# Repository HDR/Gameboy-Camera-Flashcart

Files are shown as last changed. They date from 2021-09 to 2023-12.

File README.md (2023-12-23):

## Make sure you read the License (Attribution-NonCommercial-ShareAlike 4.0 International)

Purchase on PCBWay (https://www.pcbway.com/project/shareproject/Game_Boy_Camera_Flashcart___2x1MB___FRAM__.html)

Purchase Advanced (https://www.pcbway.com/project/shareproject/Game_Boy_Camera_Flashcart_2x1MB_FRAM_Advanced_PCB_73cba77a.html)

If you want to support me for free (and get 5 USD in new user credit) you can use my PCBWay [Referral link](https://www.pcbway.com/setinvite.aspx?inviteid=388393) when signing up on PCBWay



PCBWay Referral (https://www.pcbway.com/setinvite.aspx?inviteid=388393)

**Make sure you read the License!**

**Flashing:**

Flashing has only been tested with a [GBxCart](https://www.insidegadgets.com/projects/gbxcart-rw/), flashing both 1MB sections requires [this custom software](GBxCart_RW_GB_Camera_2x1MB_Flasher.zip), which is a modified version of InsideGadget's 2x2MB MBC3 software, or [FlashGBX](https://github.com/lesserkuma/FlashGBX/releases) v3.2 and above.

**BOM:**

| Reference | Part Number | Description |
|-|-|-|
| C1 | [4x4.5mm 22uF](https://www.aliexpress.com/item/32377971645.html) | 22uF 16V 4x4.5 Electrolytic Capacitor |
| C2, C3, C4, C12, C13 | [TCC0603X7R104J500CT](https://www.lcsc.com/product-detail/Multilayer-Ceramic-Capacitors-MLCC-SMD-SMT_CCTC-TCC0603X7R104J500CT_C282518.html) | 100nF 0603 Capacitor |
| C5, C6, C7, C8, C9, C10, C11 | [CC0402KRX7R7BB104](https://lcsc.com/product-detail/Multilayer-Ceramic-Capacitors-MLCC-SMD-SMT_YAGEO-CC0402KRX7R7BB104_C60474.html) | 100nF 0402 Capacitor |
| C14, C15 | [CC0603JRNPO9BN220](https://www.lcsc.com/product-detail/Multilayer-Ceramic-Capacitors-MLCC-SMD-SMT_YAGEO-CC0603JRNPO9BN220_C105620.html) | 22pF 0603 Capacitor |
| R1 | [RC0603JR-071KL](https://www.lcsc.com/product-detail/Chip-Resistor-Surface-Mount_YAGEO-RC0603JR-071KL_C14676.html) | 1K Ω 0603 Resistor |
| D1 | Diode | Harvest D2 from original cartridge |
| J1 | [B9B-ZR-SM4-TF](https://www.aliexpress.com/item/32920487056.html) | Camera Connector, Harvest or buy (JST ZH1.5MM 9 Pin) |
| SW1 | [K3-1296S-E1](https://www.lcsc.com/product-detail/Slide-Switches_Korean-Hroparts-Elec-K3-1296S-E1_C128955.html)| SPDT Switch (For 2x1MB Rom Switching) |
| U1 | MAC-GBD | Harvest U1 from original cartridge |
| U2 | [AM29F016](https://www.aliexpress.com/item/33043533022.html) | 2MB Flash |
| U3 | [FM28V100](https://www.aliexpress.com/item/4001322883101.html) | 1MB FRAM |
| U4 | [TPRT9013-33G](https://www.lcsc.com/product-detail/Linear-Voltage-Regulators-LDO_TECH-PUBLIC-TPRT9013-33GB_C587158.html) | 3.3V Voltage Regulator |

[Interactive BOM](https://martinrefseth.com/ibom/Game%20Boy%20Camera%20Flashcart)

Makes use of [djedditt's](https://github.com/djedditt/s) [gamepak footprint](https://github.com/djedditt/kicad-gamepaks)

Looking for a ready to use flashcart? check out InsideGadgets custom flashcart, the [Insidegadgets' PicNRec AIO](https://shop.insidegadgets.com/product/gameboy-camera-picnrec-aio/)
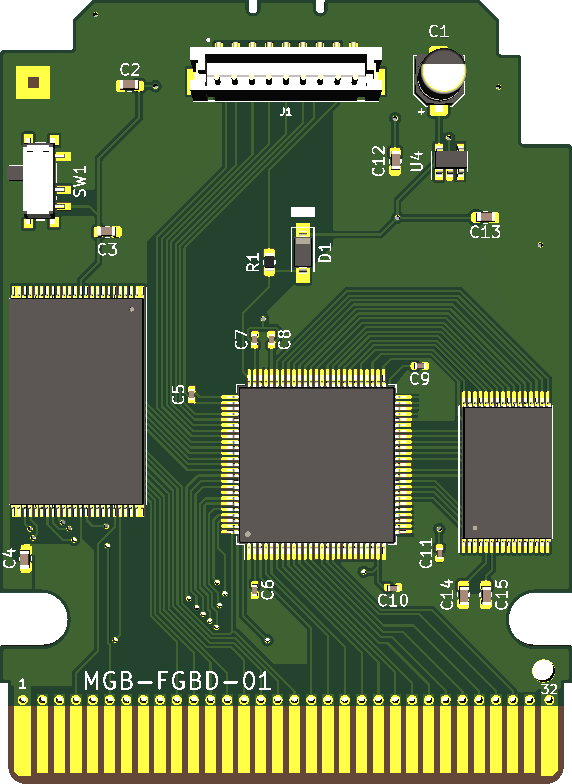
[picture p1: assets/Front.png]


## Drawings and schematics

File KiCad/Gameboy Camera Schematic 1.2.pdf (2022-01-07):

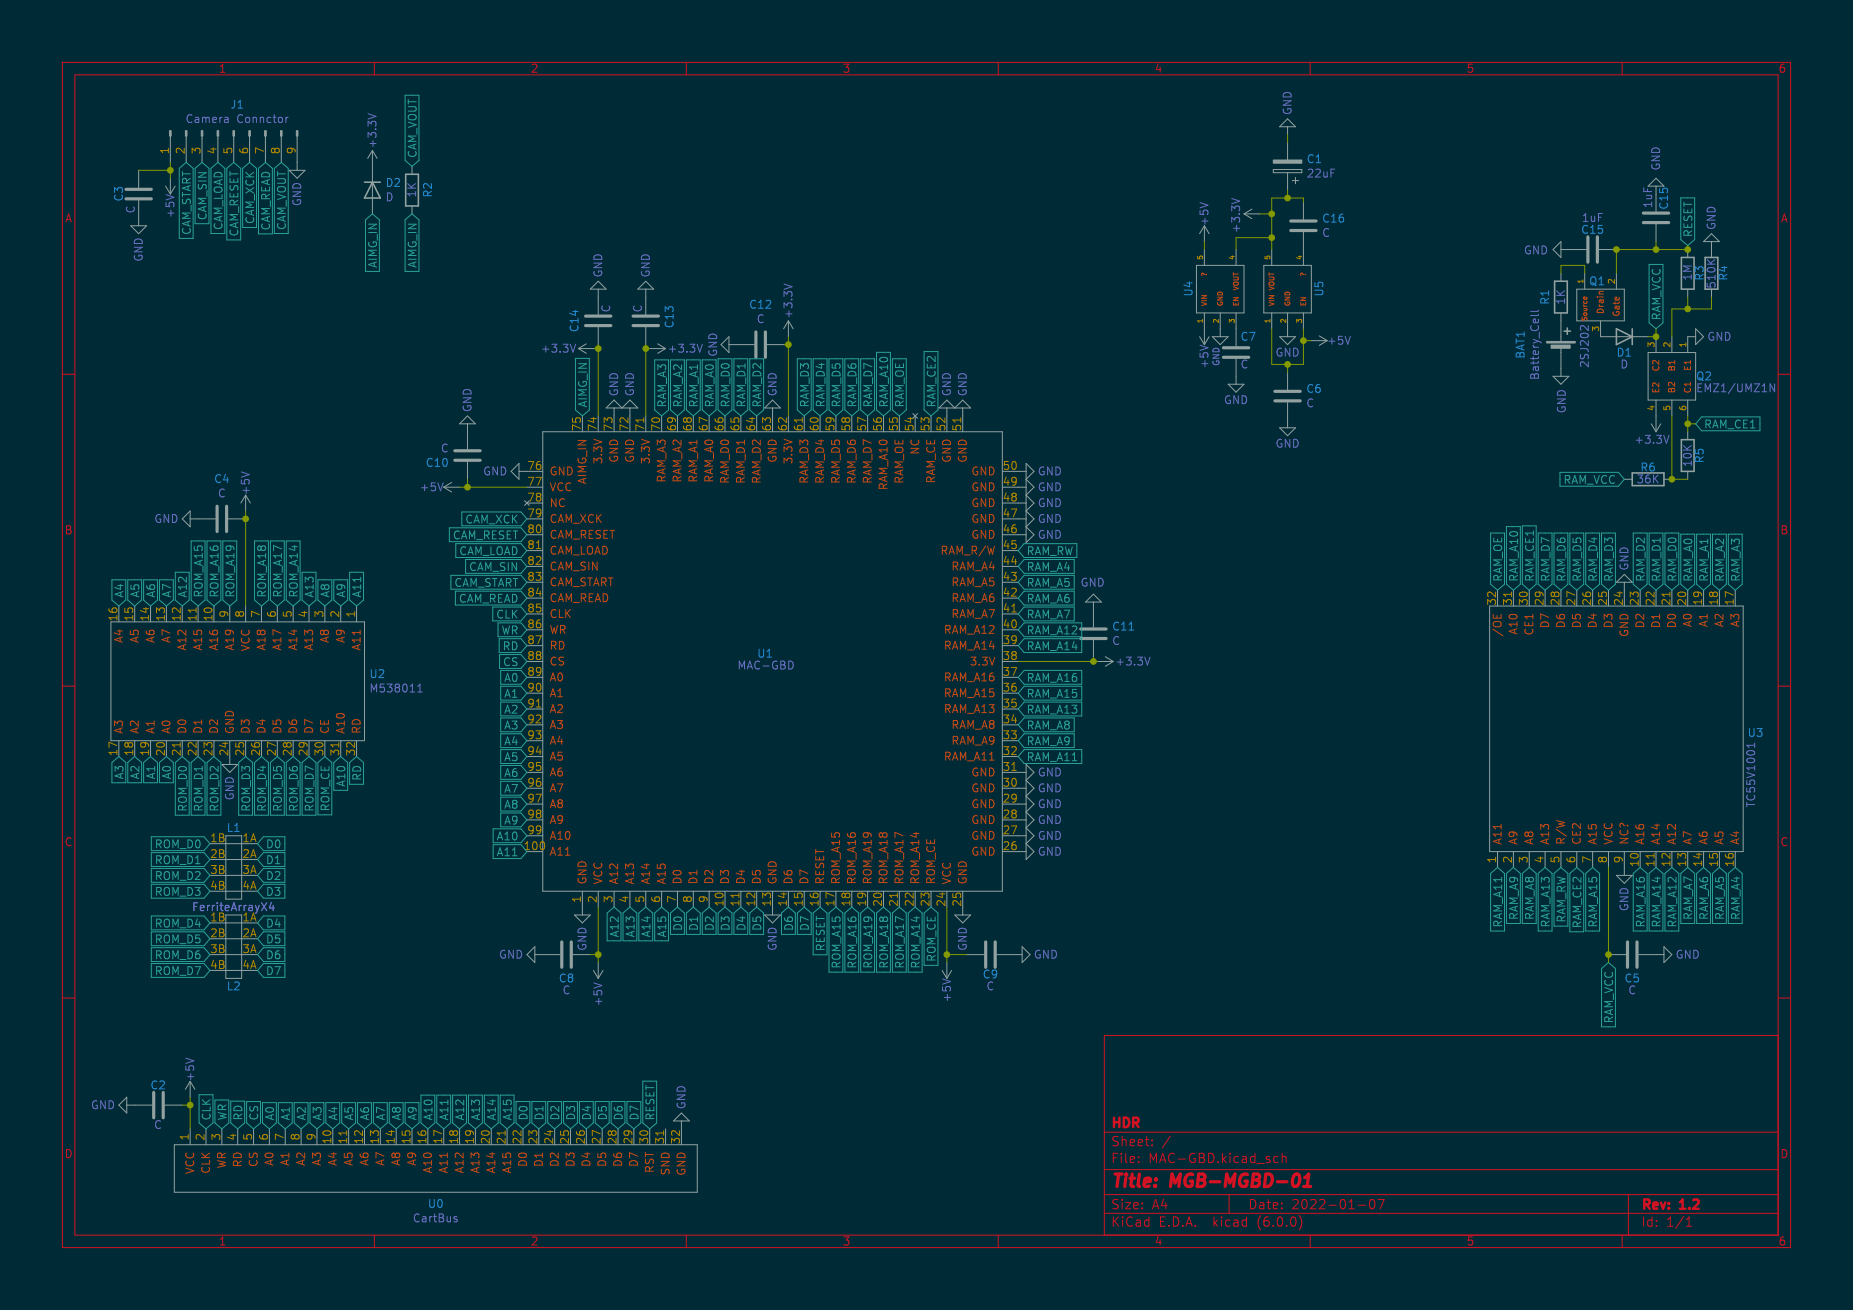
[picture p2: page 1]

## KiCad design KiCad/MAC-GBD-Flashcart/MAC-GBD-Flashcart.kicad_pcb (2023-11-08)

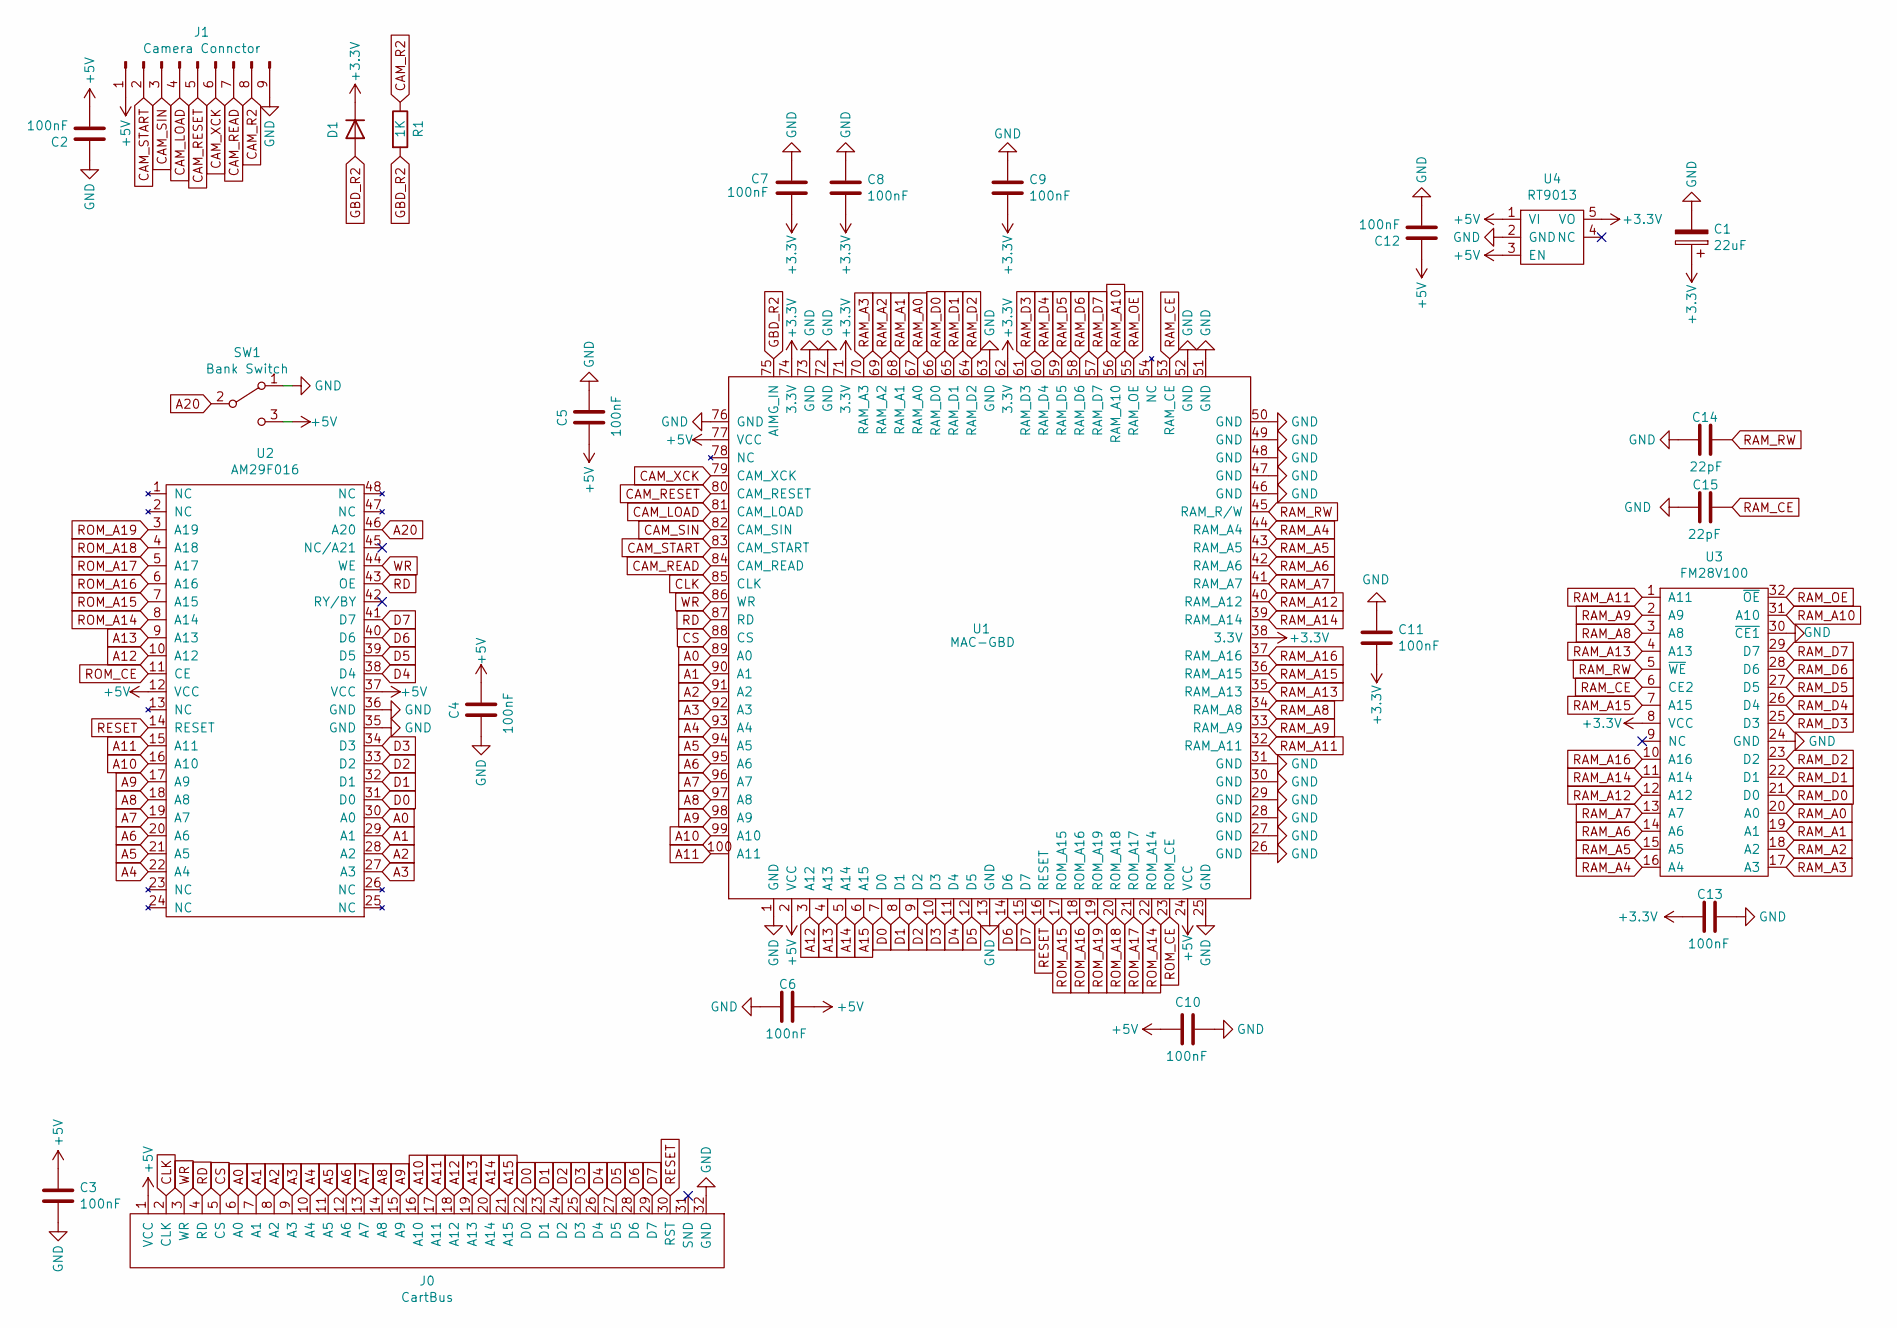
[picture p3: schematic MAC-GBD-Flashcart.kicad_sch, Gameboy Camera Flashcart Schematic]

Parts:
C1: 22uF; CP_Elec_4x4.5
C2, C3, C4, C12, C13: 100nF; C_0603_1608Metric
C5, C6, C7, C8, C9, C10, C11: 100nF; C_0402_1005Metric
C14, C15: 22pF; C_0603_1608Metric
D1: Diode; D_SOD-123
J0: CartBus; GameBoy_GamePak_CGB-002_P1.50mm_Edge
J1: Camera Connctor; JST_B9B-ZR-SM4-TF
R1: 1K; R_0603_1608Metric
SW1: Bank Switch; SW_SPDT-K3-1296S-E1
U1: MAC-GBD; LQFP-100_14x14mm_P0.5mm
U2: AM29F016; AM29F0XX
U3: FM28V100; TSOP-I-32_11.8x8mm_P0.5mm
U4: RT9013; SOT-23-5

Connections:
+3V3: C1.1, C7.1, C8.2, C9.2, C11.2, C13.2, D1.1 (K), U1.38 (3.3V), U1.62 (3.3V), U1.71 (3.3V), U1.74 (3.3V), U3.8 (VCC), U4.5 (VO)
+5V: C2.2, C3.1, C4.2, C5.1, C6.1, C10.2, C12.1, J0.1 (VCC), J1.1, SW1.3 (B), U1.2 (VCC), U1.24 (VCC), U1.77 (VCC), U2.12 (VCC), U2.37 (VCC), U4.1 (VI), U4.3 (EN); also elsewhere on the board
A0: J0.6 (A0), U1.89 (A0), U2.30 (A0); also elsewhere on the board
A1: J0.7 (A1), U1.90 (A1), U2.29 (A1); also elsewhere on the board
A2: J0.8 (A2), U1.91 (A2), U2.28 (A2); also elsewhere on the board
A3: J0.9 (A3), U1.92 (A3), U2.27 (A3); also elsewhere on the board
A4: J0.10 (A4), U1.93 (A4), U2.22 (A4); also elsewhere on the board
A5: J0.11 (A5), U1.94 (A5), U2.21 (A5); also elsewhere on the board
A6: J0.12 (A6), U1.95 (A6), U2.20 (A6); also elsewhere on the board
A7: J0.13 (A7), U1.96 (A7), U2.19 (A7); also elsewhere on the board
A8: J0.14 (A8), U1.97 (A8), U2.18 (A8); also elsewhere on the board
A9: J0.15 (A9), U1.98 (A9), U2.17 (A9); also elsewhere on the board
A10: J0.16 (A10), U1.99 (A10), U2.16 (A10); also elsewhere on the board
A11: J0.17 (A11), U1.100 (A11), U2.15 (A11); also elsewhere on the board
A12: J0.18 (A12), U1.3 (A12), U2.10 (A12); also elsewhere on the board
A13: J0.19 (A13), U1.4 (A13), U2.9 (A13); also elsewhere on the board
A14: J0.20 (A14), U1.5 (A14); also elsewhere on the board
A15: J0.21 (A15), U1.6 (A15); also elsewhere on the board
CAM_LOAD: J1.4, U1.81 (CAM_LOAD)
CAM_R2: J1.8, R1.1
CAM_READ: J1.7, U1.84 (CAM_READ)
CAM_RESET: J1.5, U1.80 (CAM_RESET)
CAM_SIN: J1.3, U1.82 (CAM_SIN)
CAM_START: J1.2, U1.83 (CAM_START)
CAM_XCK: J1.6, U1.79 (CAM_XCK)
CLK: J0.2 (CLK~), U1.85 (CLK); also elsewhere on the board
CS: J0.5 (CS), U1.88 (CS); also elsewhere on the board
D0: J0.22 (D0), U1.7 (D0), U2.31 (D0); also elsewhere on the board
D1: J0.23 (D1), U1.8 (D1), U2.32 (D1); also elsewhere on the board
D2: J0.24 (D2), U1.9 (D2), U2.33 (D2); also elsewhere on the board
D3: J0.25 (D3), U1.10 (D3), U2.34 (D3); also elsewhere on the board
D4: J0.26 (D4), U1.11 (D4), U2.38 (D4); also elsewhere on the board
D5: J0.27 (D5), U1.12 (D5), U2.39 (D5); also elsewhere on the board
D6: J0.28 (D6), U1.14 (D6), U2.40 (D6); also elsewhere on the board
D7: J0.29 (D7), U1.15 (D7), U2.41 (D7); also elsewhere on the board
GBD_R2: D1.2 (A), R1.2, U1.75 (AIMG_IN)
unnamed: SW1.2 (C), U2.46 (A20)
RAM_A0: U1.67 (RAM_A0), U3.20 (A0)
RAM_A1: U1.68 (RAM_A1), U3.19 (A1)
RAM_A2: U1.69 (RAM_A2), U3.18 (A2)
RAM_A3: U1.70 (RAM_A3), U3.17 (A3)
RAM_A4: U1.44 (RAM_A4), U3.16 (A4)
RAM_A5: U1.43 (RAM_A5), U3.15 (A5)
RAM_A6: U1.42 (RAM_A6), U3.14 (A6)
RAM_A7: U1.41 (RAM_A7), U3.13 (A7)
RAM_A8: U1.34 (RAM_A8), U3.3 (A8)
RAM_A9: U1.33 (RAM_A9), U3.2 (A9)
RAM_A10: U1.56 (RAM_A10), U3.31 (A10)
RAM_A11: U1.32 (RAM_A11), U3.1 (A11)
RAM_A12: U1.40 (RAM_A12), U3.12 (A12)
RAM_A13: U1.35 (RAM_A13), U3.4 (A13)
RAM_A14: U1.39 (RAM_A14), U3.11 (A14)
RAM_A15: U1.36 (RAM_A15), U3.7 (A15)
RAM_A16: U1.37 (RAM_A16), U3.10 (A16)
RAM_D0: U1.66 (RAM_D0), U3.21 (D0)
RAM_D1: U1.65 (RAM_D1), U3.22 (D1)
RAM_D2: U1.64 (RAM_D2), U3.23 (D2)
RAM_D3: U1.61 (RAM_D3), U3.25 (D3)
RAM_D4: U1.60 (RAM_D4), U3.26 (D4)
RAM_D5: U1.59 (RAM_D5), U3.27 (D5)
RAM_D6: U1.58 (RAM_D6), U3.28 (D6)
RAM_D7: U1.57 (RAM_D7), U3.29 (D7)
RAM_OE: U1.55 (RAM_OE), U3.32 (~OE)
RAM_RW: C14.1, U1.45 (RAM_R/W), U3.5 (~WE)
RD: J0.4 (RD), U1.87 (RD), U2.43 (OE); also elsewhere on the board
RESET: J0.30 (RST), U1.16 (RESET), U2.14 (RESET); also elsewhere on the board
ROM_A14: U1.22 (ROM_A14), U2.8 (A14)
ROM_A15: U1.17 (ROM_A15), U2.7 (A15)
ROM_A16: U1.18 (ROM_A16), U2.6 (A16)
ROM_A17: U1.21 (ROM_A17), U2.5 (A17)
ROM_A18: U1.20 (ROM_A18), U2.4 (A18)
ROM_A19: U1.19 (ROM_A19), U2.3 (A19)
ROM_CE: U1.23 (ROM_CE), U2.11 (CE)
WR: J0.3 (WR), U1.86 (WR), U2.44 (WE); also elsewhere on the board

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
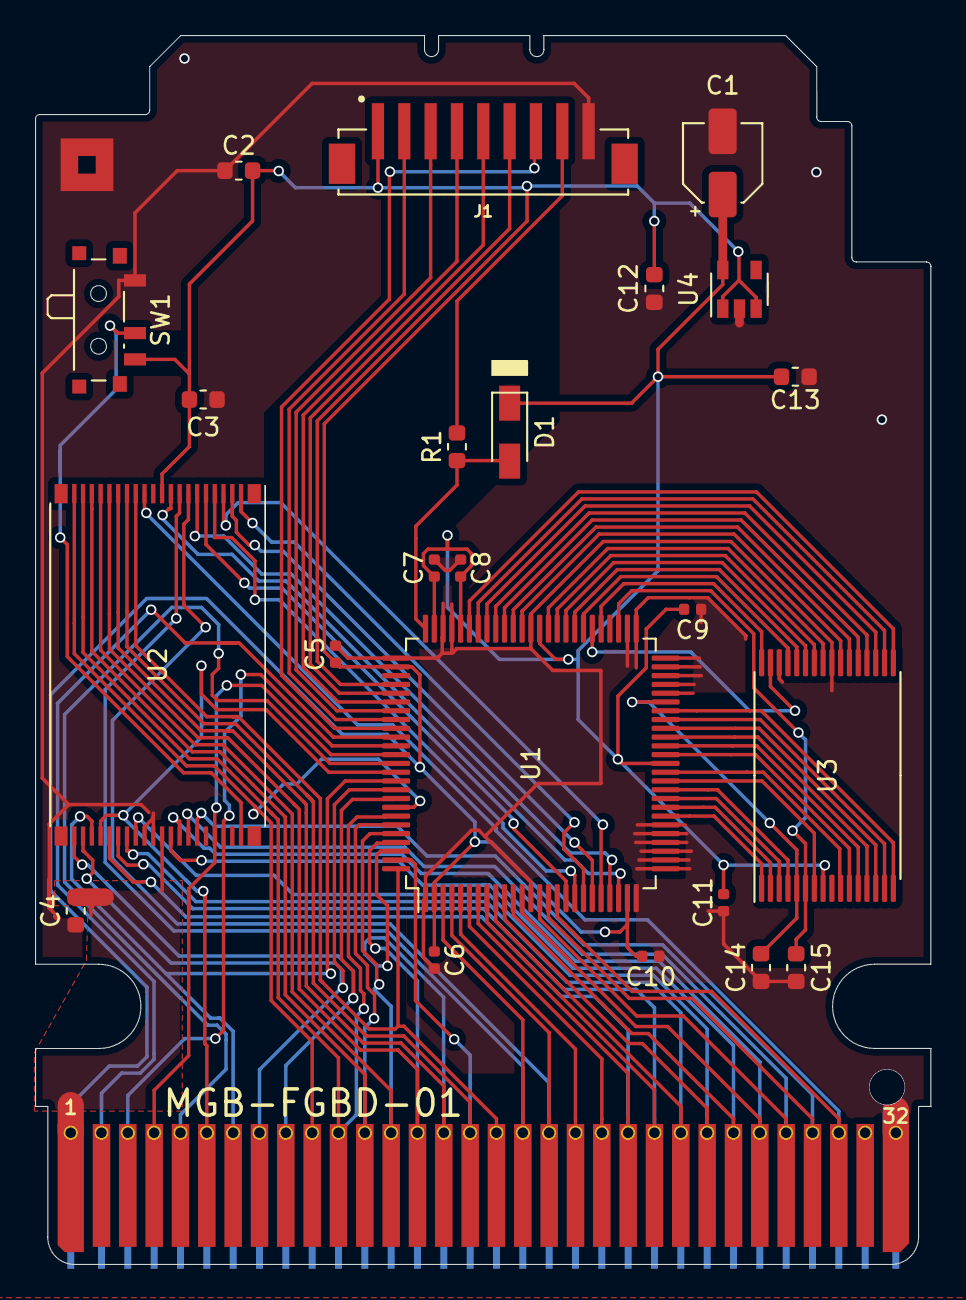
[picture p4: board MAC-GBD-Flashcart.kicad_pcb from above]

Board: 2 copper layers, 51.0 x 70.0 mm, 25 parts (0 on the bottom side), 76 nets.

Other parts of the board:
PAD*: Nintendo_3x3_GNDPad
U0: CartBus; GameBoy_GamePak_CGB-002_P1.50mm_Edge

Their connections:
+5V: U0.1; also elsewhere on the board
A0: U0.6; also elsewhere on the board
A1: U0.7; also elsewhere on the board
A2: U0.8; also elsewhere on the board
A3: U0.9; also elsewhere on the board
A4: U0.10; also elsewhere on the board
A5: U0.11; also elsewhere on the board
A6: U0.12; also elsewhere on the board
A7: U0.13; also elsewhere on the board
A8: U0.14; also elsewhere on the board
A9: U0.15; also elsewhere on the board
A10: U0.16; also elsewhere on the board
A11: U0.17; also elsewhere on the board
A12: U0.18; also elsewhere on the board
A13: U0.19; also elsewhere on the board
A14: U0.20; also elsewhere on the board
A15: U0.21; also elsewhere on the board
CLK: U0.2; also elsewhere on the board
CS: U0.5; also elsewhere on the board
D0: U0.22; also elsewhere on the board
D1: U0.23; also elsewhere on the board
D2: U0.24; also elsewhere on the board
D3: U0.25; also elsewhere on the board
D4: U0.26; also elsewhere on the board
D5: U0.27; also elsewhere on the board
D6: U0.28; also elsewhere on the board
D7: U0.29; also elsewhere on the board
RD: U0.4; also elsewhere on the board
RESET: U0.30; also elsewhere on the board
WR: U0.3; also elsewhere on the board

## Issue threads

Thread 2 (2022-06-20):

Hope to upload Gerbers to Advanced PCB

theBillLee, 2022-06-20:
Now BCPWay only has Standard PCB, hope to upload Gerbers to Advanced PCB Thanks

HDR, 2022-06-20:
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

theBillLee, 2022-06-20:
I didn't make that clear. I know it's available at PCBWay. But PCBWay's is Standard PCB, I hope you can upload to PCBWay Advanced PCB. not hope you upload to Github

HDR, 2022-06-20:
Ah gotcha, i've put up an advanced version here https://www.pcbway.com/project/shareproject/Game_Boy_Camera_Flashcart_2x1MB_FRAM_Advanced_PCB_73cba77a.html

Closed 2022-06-20.

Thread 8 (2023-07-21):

Question: tollerance on C1

remy, 2023-07-21:
I'm trying to build my own, but I cannot for the life of me find an smd cap with the 4x4.5 footprint (I've tried alix - though the search filters aren't great - and the one linked doesn't post to the UK, but also doesn't mention the footprint. -- I've also tried LCSC and I've tried rs-components).

I've found a lot of 4x5.4, but that's the closest.

Would that still fit do you (or anyone else) think?

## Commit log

2020-08-30 Create Gameboy Camera Schematic 1.0.pdf
    Add original board schematic
2021-07-31 Update Schematic
    Update schematic to fix some issues.
2021-09-23 Add board image
2022-01-07 Update Schematic
    Add missing pin name for pin 75
2022-05-13 Create Gitingore, add sensor datasheet
2022-06-20 Add advanced pcb link
2023-11-08 Release Project Files
    [MAC-GBD-Flashcart.kicad_pcb, MAC-GBD-Flashcart.kicad_sch]

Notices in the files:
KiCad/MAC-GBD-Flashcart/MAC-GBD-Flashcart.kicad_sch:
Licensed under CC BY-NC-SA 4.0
